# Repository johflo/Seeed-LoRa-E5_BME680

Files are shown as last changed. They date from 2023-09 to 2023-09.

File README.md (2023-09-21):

Seeed Wio E5 LoraWan BME680 node without seperate MCU.
Data from the BM680 is sent through the Helium LoraWan network to Cayenne to visualize the measured data

PCB designed with KiCad, assembled by seeedstudio (https://github.com/Seeed-Studio)

Next steps todo:
- testing low power consumption (low current measurement equipment needed like https://github.com/nfhw/tinycurrent)
- rework pcb to shrink it
- connection to Datacake instead of directly to Helium

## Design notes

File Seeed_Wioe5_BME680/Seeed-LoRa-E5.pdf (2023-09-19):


14/07/2022

Seeed-LoRa-E5 Project
Configuration Report

## 1. Description

### 1.1. Project

Project Name | Seeed-LoRa-E5
Board Name | custom
Generated with: | STM32CubeMX 6.6.1
Date | 07/14/2022

### 1.2. MCU

MCU Series | STM32WL
MCU Line | STM32WLEx
MCU name | STM32WLE5JCIx
MCU Package | UFBGA73
MCU Pin number | 73

### 1.3. Core(s) information

Core(s) | ARM Cortex-M4

## 2. Pinout Configuration

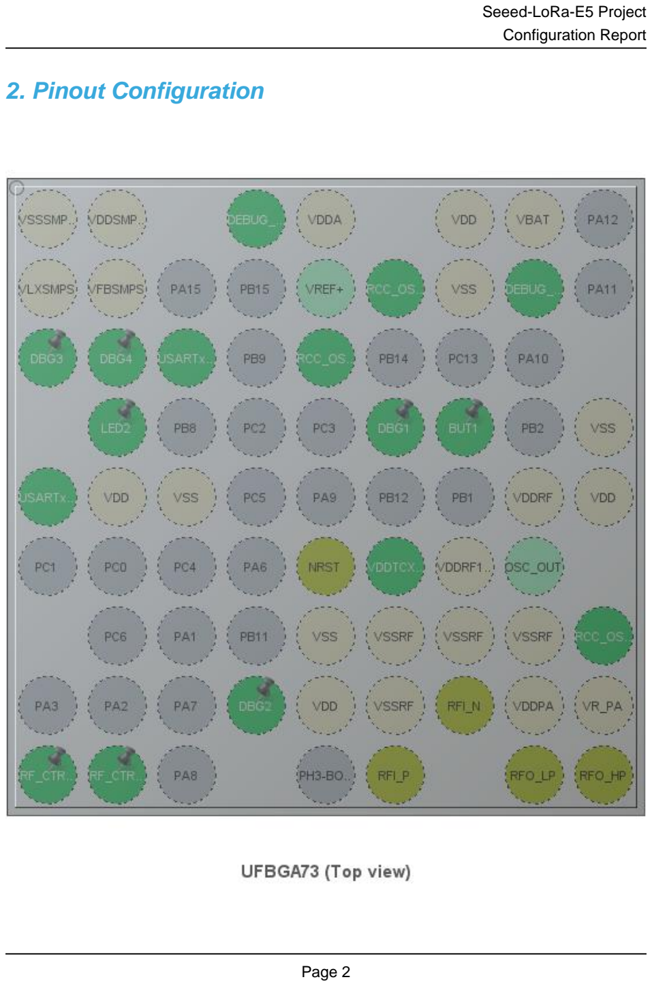
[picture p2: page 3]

## 3. Pins Configuration

Pin Number UFBGA73 | Pin Name (function after reset) | Pin Type | Alternate Function(s) | Label
A1 | VSSSMPS | Power
A2 | VDDSMPS | Power
A4 | PA14 | I/O | DEBUG_JTCK-SWCLK
A5 | VDDA | Power
A7 | VDD | Power
A8 | VBAT | Power
B1 | VLXSMPS | Power
B2 | VFBSMPS | Power
B6 | PC14-OSC32_IN | I/O | RCC_OSC32_IN
B7 | VSS | Power
B8 | PA13 | I/O | DEBUG_JTMS-SWDIO
C1 | PB3 * | I/O | GPIO_Output | DBG3
C2 | PB4 * | I/O | GPIO_Output | DBG4
C3 | PB7 | I/O | USART1_RX | USARTx_RX
C5 | PC15-OSC32_OUT | I/O | RCC_OSC32_OUT
D2 | PB5 * | I/O | GPIO_Output | LED2
D6 | PA0 * | I/O | GPIO_Output | DBG1
D7 | PB13 | I/O | GPIO_EXTI13 | BUT1
D9 | VSS | Power
E1 | PB6 | I/O | USART1_TX | USARTx_TX
E2 | VDD | Power
E3 | VSS | Power
E8 | VDDRF | Power
E9 | VDD | Power
F5 | NRST | Reset
F6 | PB0-VDD_TCXO | I/O | VDDTCXO
F7 | VDDRF1V55 | Power
G5 | VSS | Power
G6 | VSSRF | Power
G7 | VSSRF | Power
G8 | VSSRF | Power
G9 | OSC_IN | MonoIO | RCC_OSC_IN
H4 | PB10 * | I/O | GPIO_Output | DBG2
H5 | VDD | Power
H6 | VSSRF | Power
H7 | RFI_N | MonoIO

Pin Number UFBGA73 | Pin Name (function after reset) | Pin Type | Alternate Function(s) | Label
H8 | VDDPA | Power
H9 | VR_PA | Power
J1 | PA4 * | I/O | GPIO_Output | RF_CTRL1
J2 | PA5 * | I/O | GPIO_Output | RF_CTRL2
J6 | RFI_P | MonoIO
J8 | RFO_LP | MonoIO
J9 | RFO_HP | MonoIO

* The pin is affected with an I/O function

## 4. Clock Tree Configuration

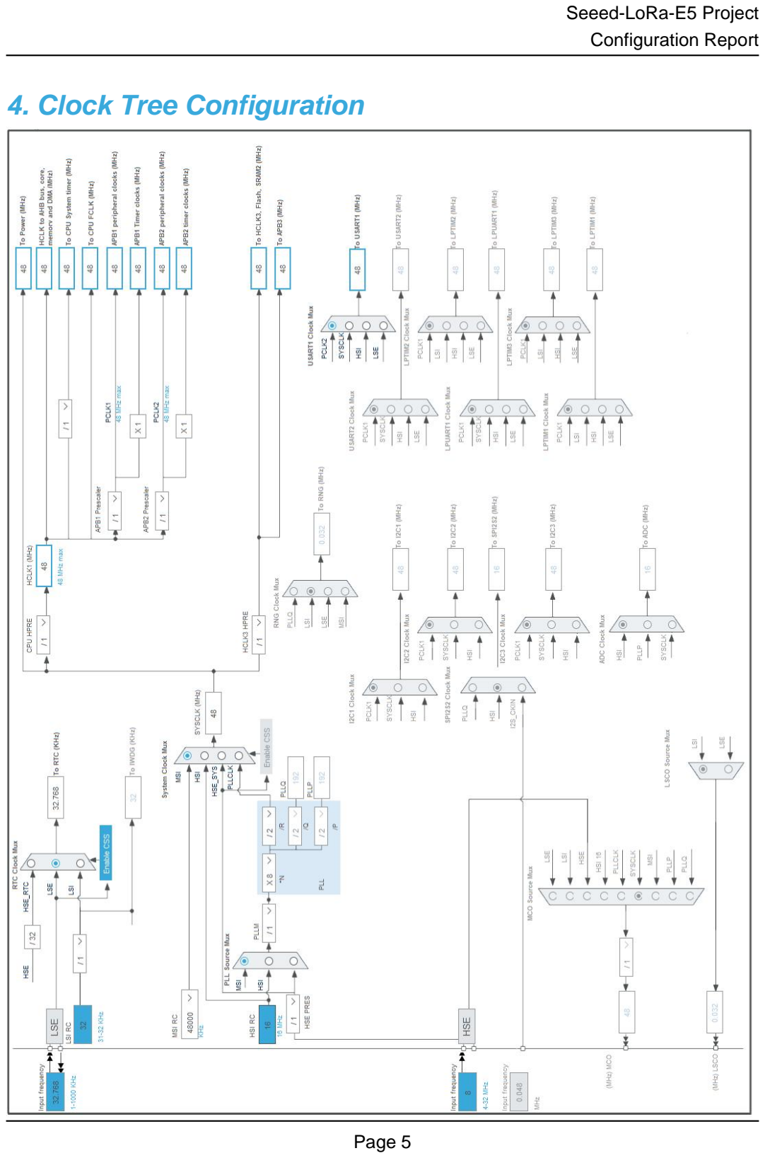
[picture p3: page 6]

## 5. Software Project

### 5.1. Project Settings

Name | Value
Project Name | Seeed-LoRa-E5
Project Folder | C:\Users\danam\STM32CubeIDE\workspace_1.7.0\Seeed-LoRa-E5
Toolchain / IDE | STM32CubeIDE
Firmware Package Name and Version | STM32Cube FW_WL V1.2.0
Application Structure | Advanced
Generate Under Root | Yes
Do not generate the main() | No
Minimum Heap Size | 0x200
Minimum Stack Size | 0x400

### 5.2. Code Generation Settings

Name | Value
STM32Cube MCU packages and embedded software | Copy only the necessary library files
Generate peripheral initialization as a pair of '.c/.h' files | Yes
Backup previously generated files when re-generating | Yes
Keep User Code when re-generating | Yes
Delete previously generated files when not re-generated | Yes
Set all free pins as analog (to optimize the power consumption) | No
Enable Full Assert | No

### 5.3. Advanced Settings - Generated Function Calls

Rank | Function Name | Peripheral Instance Name
1 | SystemClock_Config | RCC
2 | MX_GPIO_Init | GPIO
3 | MX_ADC_Init | ADC
4 | MX_RTC_Init | RTC
5 | MX_DMA_Init | DMA
6 | MX_USART1_UART_Init | USART1
7 | MX_SUBGHZ_Init | SUBGHZ
8 | MX_LoRaWAN_Init | LORAWAN

## 6. Power Consumption Calculator report

### 6.1. Microcontroller Selection

Series | STM32WL
Line | STM32WLEx
MCU | STM32WLE5JCIx
Datasheet | DS13105_Rev7

### 6.2. Parameter Selection

Temperature | 25
Vdd | 3.0

### 6.3. Battery Selection

Battery | Li-SOCL2(AAA700)
Capacity | 700.0 mAh
Self Discharge | 0.08 %/month
Nominal Voltage | 3.6 V
Max Cont Current | 10.0 mA
Max Pulse Current | 30.0 mA
Cells in series | 1
Cells in parallel | 1

### 6.4. Sequence

Step | Step1 | Step2
Mode | RUN | STOP2
Vdd | 3.0 | 3.0
Voltage Source | Battery | Battery
Range | Range1-Medium/SMPS-OFF | NoRange
Fetch Type | SRAM1 | NA
CPU Frequency | 48 MHz | 0 Hz
Clock Configuration | MSI | ALL_CLOCKS_OFF
Clock Source Frequency | 48 MHz | 0 Hz
Peripherals
Additional Cons. | 0 mA | 0 mA
Average Current | 5.65 mA | 885 nA
Duration | 0.1 ms | 0.9 ms
DMIPS | 60.0 | 0.0
Ta Max | 124.47 | 125
Category | In DS Table | In DS Table

### 6.5. Results

Sequence Time | 1 ms | Average Current | 565.8 µA
Battery Life | 1 month, 21 days, 1 hour | Average DMIPS | 60.0 DMIPS

### 6.6. Chart

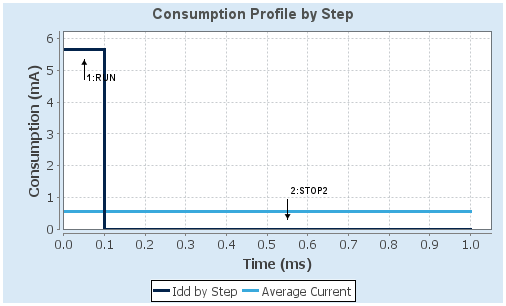
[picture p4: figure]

## 7. Peripherals and Middlewares Configuration

### 7.1. ADC

mode: Temperature Sensor Channel
mode: Vrefint Channel
7.1.1. Parameter Settings:

ADC_Settings:
Clock Prescaler | Synchronous clock mode divided by 4 *
Resolution | ADC 12-bit resolution
Calibration | Disable
Data Alignment | Right alignment
Scan Conversion Mode | Disabled
End Of Conversion Selection | End of single conversion
Low Power Auto Wait | Disabled
Auto Off | Disabled
Continuous Conversion Mode | Disabled
Discontinuous Conversion Mode | Disabled
External Trigger Conversion Source | Regular Conversion launched by software
External Trigger Conversion Edge | None
DMA Continuous Requests | Disabled
Overrun behaviour | Overrun data overwritten *
Sequencer | Sequencer set to fully configurable
SamplingTime Common 1 | 160.5 Cycles *
SamplingTime Common 2 | 160.5 Cycles *
Oversampling Mode | Disabled
Trigger Frequency | High frequency
ADC_Regular_ConversionMode:
Enable Regular Conversions | Disable

### 7.2. ADV_TRACE

mode: Enabled

### 7.3. DEBUG

JTAG and Trace: Serial Wire

### 7.4. MISC

mode: misc

### 7.5. RCC

High Speed Clock (HSE): TCXO
Low Speed Clock (LSE) : Crystal/Ceramic Resonator
7.5.1. Parameter Settings:

System Parameters:

VDD voltage (V) | 3.3
Instruction Cache | Enabled
Prefetch Buffer | Disabled
Data Cache | Enabled
Flash Latency(WS) | 2 WS (3 CPU cycle)
RCC Parameters:
HSI Calibration Value | 64
MSI Calibration Value | 0
MSI Auto Calibration | Enabled
HSE Startup Timout Value (ms) | 100
LSE Startup Timout Value (ms) | 5000
LSE Drive Capability | LSE oscillator low drive capability
Power Parameters:
Power Regulator Voltage Scale | Power Regulator Voltage Scale 1

### 7.6. RTC

mode: Activate Clock Source
mode: Activate Calendar
Alarm A: Internal Alarm A
7.6.1. Parameter Settings:

General:

Asynchronous Predivider value | RTC_PREDIV_A *
Bin Mode | Free running Binary mode *
SSRU Underflow Interrupt | Enabled
Alarm A:
Free running 32 bit value | 0
Binary AutoControl | RTC_ALARMSUBSECONDBIN_AUTOCLR_NO *
Free running 32 bit mask | SS[31:0] are compared and must match to activate alarm.

### 7.7. SEQUENCER

mode: Enabled

### 7.8. SUBGHZ

mode: Activated
7.8.1. Parameter Settings:
Baudrate Prescaler Value | 4 *

### 7.9. SYS

Timebase Source: None

### 7.10. TIMER

mode: Enabled

### 7.11. TINY_LPM

mode: Enabled

### 7.12. USART1

Mode: Asynchronous
7.12.1. Parameter Settings:

Basic Parameters:

Baud Rate | 115200
Word Length | 8 Bits (including Parity)
Parity | None
Stop Bits | 1
Advanced Parameters:
Data Direction | Receive and Transmit
Over Sampling | 16 Samples
Single Sample | Disable
ClockPrescaler | 1
Fifo Mode | Enable *
Txfifo Threshold | 1 eighth full configuration

Rxfifo Threshold | 1 eighth full configuration
Advanced Features:
Auto Baudrate | Disable
TX Pin Active Level Inversion | Disable
RX Pin Active Level Inversion | Disable
Data Inversion | Disable
TX and RX Pins Swapping | Disable
Overrun | Enable
DMA on RX Error | Enable
MSB First | Disable

### 7.13. LORAWAN

mode: Enabled
7.13.1. LoRaWAN application:

Application selection:
Application | End Node skeleton *
Application configuration recommandations | !! Please read carefully Information panel below!!

board settings:

Send Tx on Timer or Button Evt | TX_ON_TIMER
Probes Lines in Platform Settings | true *
lora_app:
Active region | LORAMAC_REGION_US915 *
Transmition duty cycle | 10000
Application user port | 2
Switch class port | 3
Default class | CLASS_A
Default handler message state | Unconfirmed message
Handler Adaptive Data Rate | On
Default activation type | OTAA
Force rejoin at each reboot | true
Default Unicast ping slots periodicity | 4
Default reponse timeout for class b and class c confirmed downlink frames in milli seconds. | 8000
sys_conf:
Trace verbose level | VLEVEL_M
Enable Application Logging | true
Disable Low Power Mode | false
Enable Sensor | false

7.13.2. LoRaWAN commissioning:

Commissioning:

Public network | true
Current network ID | 0
se-identity:
Static Device EUI | false
App/Join EUI | 01, 01, 01, 01, 01, 01, 01, 01
Application key | 9B,0C,9A,82,E6,74,A5,11,B9,E 5,26,A9,11,87,EB,84 *
Network key | 8B,0C,9A,82,E6,74,A5,11,B9,E 5,26,A9,11,87,EB,84 *
Static Device Address | false
Network session key | 2B,7E,15,16,28,AE,D2,A6,AB,F7,15,88,0 9,CF,4F,3C
Application session key | 2B,7E,15,16,28,AE,D2,A6,AB,F7,15,88,0 9,CF,4F,3C

lorawan_conf:

Enable Key read access | true
7.13.3. LoRaWAN middleware:

lorawan_conf:

Region(s) selection | please select the desired region(s) in the list below
Region Asia freq: 923 | false
Region Australia freq: 915 | false
Region China freq: 470 | false
Region China freq: 779 | false
Region Europe freq: 433 | false
Region Europe freq: 868 | true
Region Korea freq: 920 | false
Region India freq: 865 | false
Region USA freq: 915 | true
Region Russia freq: 864 | false
Enable Hybrid mode | false
Enable LoRaMAC ClassB | false
Enable the context management storage | true *
Select the LoRaWAN Link Layer specification version | v1.0.4 *
radio_conf:

Radio maximum wakeup time (in ms) | 1
radio_board_if:
Select radio Driver | Bsp via extSettings *
mw_log_conf:
Enable Middleware log | true
7.13.4. Platform Settings:
ADC | ADC
RTC | RTC
USART | USART1
Debug Line 1 | PA0
Debug Line 2 | PB10
Debug Line 3 | PB3
Debug Line 4 | PB4

* User modified value

## 8. System Configuration

### 8.1. GPIO configuration

IP | Pin | Signal | GPIO mode | GPIO pull/up pull down | Max Speed | User Label
DEBUG | PA14 | DEBUG_JTCK-SWCLK | n/a | n/a | n/a
| PA13 | DEBUG_JTMS-SWDIO | n/a | n/a | n/a
RCC | PC14-OSC32_IN | RCC_OSC32_IN | n/a | n/a | n/a
| PC15-OSC32_OU T | RCC_OSC32_O UT | n/a | n/a | n/a
| PB0-VDD_TCXO | VDDTCXO | n/a | n/a | n/a
| OSC_IN | RCC_OSC_IN | n/a | n/a | n/a
USART1 | PB7 | USART1_RX | Alternate Function Push Pull | No pull-up and no pull-down | Very High * | USARTx_RX
| PB6 | USART1_TX | Alternate Function Push Pull | No pull-up and no pull-down | Very High * | USARTx_TX
| | | | | * | DBG3
| PB4 | GPIO_Output | Output Push Pull | No pull-up and no pull-down | Very High * | DBG4
| PB5 | GPIO_Output | Output Push Pull | No pull-up and no pull-down | Very High * | LED2
| PA0 | GPIO_Output | Output Push Pull | No pull-up and no pull-down | Very High * | DBG1
| PB13 | GPIO_EXTI13 | External Interrupt Mode with Falling edge trigger detection | Pull-up * | n/a | BUT1
| PB10 | GPIO_Output | Output Push Pull | No pull-up and no pull-down | Very High * | DBG2
| PA4 | GPIO_Output | Output Push Pull | No pull-up and no pull-down | Very High * | RF_CTRL1
| PA5 | GPIO_Output | Output Push Pull | No pull-up and no pull-down | Very High * | RF_CTRL2
GPIO | PB3 | GPIO_Output | Output Push Pull | No pull-up and no pull-down | Very High

### 8.2. DMA configuration

DMA request | Stream | Direction | Priority
USART1_TX | DMA1_Channel1 | Memory To Peripheral | Low

USART1_TX: DMA1_Channel1 DMA request Settings:

Mode: | Normal
Peripheral Increment: | Disable
Memory Increment: | Enable *
Peripheral Data Width: | Byte
Memory Data Width: | Byte

### 8.3. NVIC configuration

8.3.1. NVIC
Interrupt Table | Enable | Preenmption Priority | SubPriority
Non maskable interrupt | true | 0 | 0
Hard fault interrupt | true | 0 | 0
Memory management fault | true | 0 | 0
Prefetch fault, memory access fault | true | 0 | 0
Undefined instruction or illegal state | true | 0 | 0
System service call via SWI instruction | true | 0 | 0
Debug monitor | true | 0 | 0
Pendable request for system service | true | 0 | 0
System tick timer | true | 15 | 0
RTC Tamper, RTC TimeStamp, LSECSS and RTC SSRU Interrupts | true | 0 | 0
DMA1 Channel 1 Interrupt | true | 2 | 0
USART1 Interrupt | true | 2 | 0
EXTI Lines [15:10] Interrupt | true | 0 | 0
RTC Alarms (A and B) Interrupt | true | 0 | 0
SUBGHZ Radio Interrupt | true | 0 | 0
PVD and PVM detector | | unused
FLASH (CFI) global Interrupt | | unused
RCC Interrupt | | unused
ADC Interrupt | | unused
8.3.2. NVIC Code generation

Enabled interrupt Table Select for init sequence ordering

| | Generate IRQ
| | handler | Call HAL handler
Non maskable interrupt | false | true | false
Hard fault interrupt | false | true | false
Memory management fault | false | true | false
Prefetch fault, memory access fault | false | true | false
Undefined instruction or illegal state | false | true | false
System service call via SWI instruction | false | true | false
Debug monitor | false | true | false
Pendable request for system service | false | true | false
System tick timer | false | true | false
RTC Tamper, RTC TimeStamp, LSECSS and RTC SSRU Interrupts | false | true | true
DMA1 Channel 1 Interrupt | false | true | true
USART1 Interrupt | false | true | true

Enabled interrupt Table | Select for init sequence ordering | Generate IRQ handler | Call HAL handler
EXTI Lines [15:10] Interrupt | false | true | true
RTC Alarms (A and B) Interrupt | false | true | true
SUBGHZ Radio Interrupt | false | true | true

* User modified value

## 9. System Views

9.1. Category view
9.1.1. Current

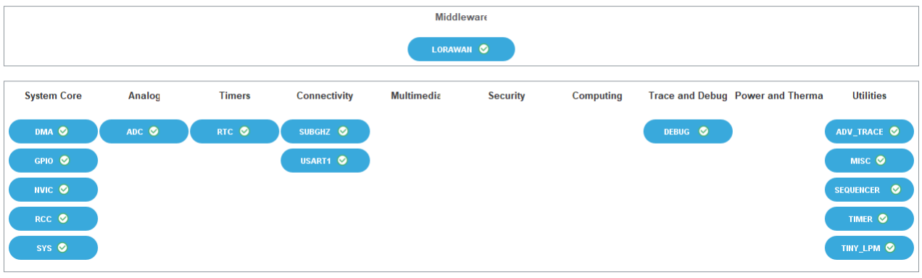
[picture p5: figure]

## 10. Docs & Resources

Type | Link
Presentations | https://www.st.com/resource/en/product_presentation/stm32-stm8_embedded_software_solutions.pdf
Presentations | https://www.st.com/resource/en/product_presentation/stm32_eval-tools_portfolio.pdf
Presentations | https://www.st.com/resource/en/product_presentation/stm32_stm8_functi onal-safety-packages.pdf
Presentations | https://www.st.com/resource/en/product_presentation/stm32-stm8_software_development_tools.pdf
Presentations | https://www.st.com/resource/en/product_presentation/microcontrollers_stm32wl_series_product_overview.pdf
Presentations | https://www.st.com/resource/en/product_presentation/stm32cubemonitor-wireless-longrange_rftest.pdf
Flyers | https://www.st.com/resource/en/flyer/flnucleolrwan.pdf
Flyers | https://www.st.com/resource/en/flyer/flstm32nucleo.pdf
Flyers | https://www.st.com/resource/en/flyer/flstm32wl.pdf
Flyers | https://www.st.com/resource/en/flyer/flstm32wbvl.pdf
Application Notes | https://www.st.com/resource/en/application_note/an1181-electrostatic-discharge-sensitivity-measurement-stmicroelectronics.pdf
Application Notes | https://www.st.com/resource/en/application_note/an1709-emc-design-guide-for-stm8-stm32-and-legacy-mcus-stmicroelectronics.pdf
Application Notes | https://www.st.com/resource/en/application_note/an2606-stm32-microcontroller-system-memory-boot-mode-stmicroelectronics.pdf
Application Notes | https://www.st.com/resource/en/application_note/an2639-soldering-recommendations-and-package-information-for-leadfree-ecopack-mcus-and-mpus-stmicroelectronics.pdf
Application Notes | https://www.st.com/resource/en/application_note/an2834-how-to-get-the-best-adc-accuracy-in-stm32-microcontrollers-stmicroelectronics.pdf
Application Notes | https://www.st.com/resource/en/application_note/an2867-oscillator-design-guide-for-stm8afals-stm32-mcus-and-mpus-stmicroelectronics.pdf

Application Notes | https://www.st.com/resource/en/application_note/an3126-audio-and-waveform-generation-using-the-dac-in-stm32-products-stmicroelectronics.pdf
Application Notes | https://www.st.com/resource/en/application_note/an3155-usart-protocol-used-in-the-stm32-bootloader-stmicroelectronics.pdf
Application Notes | https://www.st.com/resource/en/application_note/an4013-stm32-crossseries-timer-overview-stmicroelectronics.pdf
Application Notes | https://www.st.com/resource/en/application_note/an4229-how-to-implement-a-vocoder-solution-using-stm32-microcontrollers-stmicroelectronics.pdf
Application Notes | https://www.st.com/resource/en/application_note/an4286-spi-protocol-used-in-the-stm32-bootloader-stmicroelectronics.pdf
Application Notes | https://www.st.com/resource/en/application_note/an4655-virtually-increasing-the-number-of-serial-communication-peripherals-in-stm32-applications-stmicroelectronics.p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
Application Notes | https://www.st.com/resource/en/application_note/an4750-handling-of-soft-errors-in-stm32-applications-stmicroelectronics.pdf
Application Notes | https://www.st.com/resource/en/application_note/an4759-using-the-hardware-realtime-clock-rtc-and-the-tamper-management-unit-tamp-with-stm32-microcontrollers-stmicroe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
Application Notes | https://www.st.com/resource/en/application_note/an4776-generalpurpose-timer-cookbook-for-stm32-microcontrollers-stmicroelectronics.pdf
Application Notes | https://www.st.com/resource/en/application_note/an4803-highspeed-si-simulations-using-ibis-and-boardlevel-simulations-using-hyperlynx-si-on-stm32-mcus-and-mpus-stmic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
Application Notes | https://www.st.com/resource/en/application_note/an4894-eeprom-emulation-techniques-and-software-for-stm32-microcontrollers-stmicroelectronics.pdf
Application Notes | https://www.st.com/resource/en/application_note/an5027-interfacing-pdm-digital-microphones-using-stm32-mcus-and-mpus-stmicroelectronics.pdf
Application Notes | https://www.st.com/resource/en/application_note/an5036-thermal-management-guidelines-for-stm32-applications-stmicroelectronics.pdf
Application Notes | https://www.st.com/resource/en/application_note/an5042-precise-hse-

| frequency-and-startup-time-tuning-for-stm32-wireless-mcus-stmicroelectronics.pdf
Application Notes | https://www.st.com/resource/en/application_note/an5156-introduction-to-stm32-microcontrollers-security-stmicroelectronics.pdf
Application Notes | https://www.st.com/resource/en/application_note/an5225-usb-typec-power-delivery-using-stm32-mcus-and-mpus-stmicroelectronics.pdf
Application Notes | https://www.st.com/resource/en/application_note/an5406-how-to-build-a-lora-application-with-stm32cubewl-stmicroelectronics.pdf
Application Notes | https://www.st.com/resource/en/application_note/an5407-optimized-rf-board-layout-for-stm32wl-series-stmicroelectronics.pdf
Application Notes | https://www.st.com/resource/en/application_note/an5408-migrating-from-stm32l0-stm32l1-and-stm32l4-series-associated-with-sx12xx-transceivers-to-stm32wl-series-microc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
Application Notes | https://www.st.com/resource/en/application_note/an5409-stm32cube-mcu-package-examples-for-stm32wl-series-stmicroelectronics.pdf
Application Notes | https://www.st.com/resource/en/application_note/an5457-rf-matching-network-design-guide-for-stm32wl-series-stmicroelectronics.pdf
Application Notes | https://www.st.com/resource/en/application_note/an5480-how-to-build-a-sigfox-application-with-stm32cubewl-stmicroelectronics.pdf
Application Notes | https://www.st.com/resource/en/application_note/an5543-enhanced-methods-to-handle-spi-communication-on-stm32-devices-stmicroelectronics.pdf
Application Notes | https://www.st.com/resource/en/application_note/an5568-ultralowpower-features-of-stm32wl-series-microcontrollers-stmicroelectronics.pdf
Application Notes | https://www.st.com/resource/en/application_note/an5690-vrefbuf-peripheral-applications-and-trimming-technique-stmicroelectronics.pdf
Application Notes | https://www.st.com/resource/en/application_note/an5664-rssi-and-snr-for-lora-modulation-on-stm32wl-series-stmicroelectronics.pdf
Application Notes | https://www.st.com/resource/en/application_note/an4899-stm32-microcontroller-gpio-hardware-settings-and-lowpower-consumption-stmicroelectronics.pdf

Application Notes
for related Tools

https://www.st.com/resource/en/application_note/an1202_freertos_guidefreertos-guide-stmicroelectronics.pdf

& Software
Application Notes for related Tools & Software | https://www.st.com/resource/en/application_note/an1602_semihosting_in_truestudio-how-to-do-semihosting-in-truestudio-stmicroelectronics.pdf
Application Notes for related Tools & Software | https://www.st.com/resource/en/application_note/an1801_stm32cubeprogrammer_in_truestudio-installing-stm32cubeprogrammer-in-truestudio-stmicroelectronics.pdf
Application Notes for related Tools & Software | https://www.st.com/resource/en/application_note/atollic_editing_keyboard_shortcuts-atollic-editing-keyboard-shortcuts-stmicroelectronics.pdf
Application Notes for related Tools & Software | https://www.st.com/resource/en/application_note/iar_to_atollic_truestudio_migration_guide-truestudio-for-arm-migration-guide-iar-embedded-workbench-to-truestudio-stm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
Application Notes for related Tools & Software | https://www.st.com/resource/en/application_note/stm32cubemx_installation_in_truestudio-stm32cubemx-installation-in-truestudio-stmicroelectronics.pdf
Application Notes for related Tools & Software | https://www.st.com/resource/en/application_note/an4502-stm32-smbuspmbus-embedded-software-expansion-for-stm32cube-stmicroelectronics.pdf
Application Notes for related Tools & Software | https://www.st.com/resource/en/application_note/an4657-stm32-inapplication-programming-iap-using-the-usart-stmicroelectronics.pdf
Application Notes for related Tools & Software | https://www.st.com/resource/en/application_note/an4759-using-the-hardware-realtime-clock-rtc-and-the-tamper-management-unit-tamp-with-stm32-microcontrollers-stmicroe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
Application Notes for related Tools & Software | https://www.st.com/resource/en/application_note/an4841-digital-signal-processing-for-stm32-microcontrollers-using-cmsis-stmicroelectronics.pdf
Application Notes for related Tools & Software | https://www.st.com/resource/en/application_note/an4894-eeprom-emulation-techniques-and-software-for-stm32-microcontrollers-stmicroelectronics.pdf
Application Notes for related Tools & Software | https://www.st.com/resource/en/application_note/an5042-precise-hse-frequency-and-startup-time-tuning-for-stm32-wireless-mcus-stmicroelectronics.pdf

Application Notes for related Tools & Software | https://www.st.com/resource/en/application_note/an5054-secure-programming-using-stm32cubeprogrammer-stmicroelectronics.pdf
Application Notes for related Tools & Software | https://www.st.com/resource/en/application_note/an5360-getting-started-with-projects-based-on-the-stm32mp1-series-in-stm32cubeide-stmicroelectronics.pdf
Application Notes for related Tools & Software | https://www.st.com/resource/en/application_note/an5361-getting-started-with-projects-based-on-dualcore-stm32h7-microcontrollers-in-stm32cubeide-stmicroelectronics.pd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
Application Notes for related Tools & Software | https://www.st.com/resource/en/application_note/an5394-getting-started-with-projects-based-on-the-stm32l5-series-in-stm32cubeide-stmicroelectronics.pdf
Application Notes for related Tools & Software | https://www.st.com/resource/en/application_note/an5406-how-to-build-a-lora-application-with-stm32cubewl-stmicroelectronics.pdf
Application Notes for related Tools & Software | https://www.st.com/resource/en/application_note/an5409-stm32cube-mcu-package-examples-for-stm32wl-series-stmicroelectronics.pdf
Application Notes for related Tools & Software | https://www.st.com/resource/en/application_note/an5418-how-to-build-a-simple-usbpd-sink-application-with-stm32cubemx-stmicroelectronics.pdf
Application Notes for related Tools & Software | https://www.st.com/resource/en/application_note/an5426-migrating-graphics-middleware-projects-from-stm32cubemx-540-to-stm32cubemx-550-stmicroelectronics.pdf
Application Notes for related Tools & Software | https://www.st.com/resource/en/application_note/an5480-how-to-build-a-sigfox-application-with-stm32cubewl-stmicroelectronics.pdf
Application Notes for related Tools & Software | https://www.st.com/resource/en/application_note/an5481-lorawan-at-commands-for-stm32cubewl-stmicroelectronics.pdf
Application Notes for related Tools & Software | https://www.st.com/resource/en/application_note/an5544-integration-guide-of-sbsfu-on-stm32cubewl-including-kms-stmicroelectronics.pdf
Application Notes | https://www.st.com/resource/en/application_note/an5554-lorawan-

for related Tools & Software | firmware-update-over-the-air-with-stm32cubewl-stmicroelectronics.pdf
Application Notes for related Tools & Software | https://www.st.com/resource/en/application_note/an5564-getting-started-with-projects-based-on-dualcore-stm32wl-microcontrollers-in-stm32cubeide-stmicroelectronics.pd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
Application Notes for related Tools & Software | https://www.st.com/resource/en/application_note/an5566-rf-certification-process-for-nucleowl55jc-stmicroelectronics.pdf
Application Notes for related Tools & Software | https://www.st.com/resource/en/application_note/an5682-how-to-secure-lorawan-and-sigfox-with-stm32cubewl-stmicroelectronics.pdf
Application Notes for related Tools & Software | https://www.st.com/resource/en/application_note/an5687-longpacket-operation-with-stm32cubewl-stmicroelectronics.pdf
Application Notes for related Tools & Software | https://www.st.com/resource/en/application_note/an5731-stm32cubemx-and-stm32cubeide-threadsafe-solution-stmicroelectronics.pdf
Errata Sheets | https://www.st.com/resource/en/errata_sheet/es0506-stm32wle5xx-stm32wle4xx-device-errata-stmicroelectronics.pdf
Datasheet | https://www.st.com/resource/en/datasheet/dm00648230.pdf
Programming Manuals | https://www.st.com/resource/en/programming_manual/pm0214-stm32-cortexm4-mcus-and-mpus-programming-manual-stmicroelectronics.pdf
Programming Manuals | https://www.st.com/resource/en/programming_manual/pm0223-cortexm0-programming-manual-for-stm32l0-stm32g0-stm32wl-and-stm32wb-series-stmicroelectronics.pdf
Reference Manuals | https://www.st.com/resource/en/reference_manual/rm0461-stm32wlex-advanced-armbased-32bit-mcus-with-subghz-radio-solution-stmicroelectronics.pdf
Technical Notes & Articles | https://www.st.com/resource/en/technical_note/tn1163-description-of-wlcsp-for-microcontrollers-and-recommendations-for-its-use-stmicroelectronics.pdf
Technical Notes & Articles | https://www.st.com/resource/en/technical_note/tn1204-tape-and-reel-shipping-media-for-stm32-microcontrollers-in-bga-packages-stmicroelectronics.pdf

Technical Notes & Articles | https://www.st.com/resource/en/technical_note/tn1205-tape-and-reel-shipping-media-for-stm8-and-stm32-microcontrollers-in-fpn-packages-stmicroelectronics.pdf
Technical Notes & Articles | https://www.st.com/resource/en/technical_note/tn1206-tape-and-reel-shipping-media-for-stm8-and-stm32-microcontrollers-in-qfp-packages-stmicroelectronics.pdf
Technical Notes & Articles | https://www.st.com/resource/en/technical_note/tn1207-tape-and-reel-shipping-media-for-stm8-and-stm32-microcontrollers-in-so-packages-stmicroelectronics.pdf
Technical Notes & Articles | https://www.st.com/resource/en/technical_note/tn1208-tape-and-reel-shipping-media-for-stm8-and-stm32-microcontrollers-in-tssop-and-ssop-packages-stmicroelectronics.p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

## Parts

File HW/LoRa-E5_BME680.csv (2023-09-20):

Item | Qty | Reference(s) | Value | LibPart | Footprint | Datasheet | MPN | SKU
 |  | AE1 | Antenna | Device:Antenna | Sonstige:Johanson 0868AT43A0020 | ~ | 0868AT43A0020
 |  | BT1 | Battery_Cell | Device:Battery_Cell | Battery:BatteryHolder_Keystone_3008_1x2450 | ~ | MY-2450-01
 |  | C1 | 100nF | Device:C | Capacitor_SMD:C_0402_1005Metric | ~ |  | 302010004
 |  | C3 | 4.7µF | Device:C | Capacitor_SMD:C_0402_1005Metric | ~ |  | 302010111
 |  | C4 | 100nF | Device:C | Capacitor_SMD:C_0402_1005Metric | ~ |  | 302010004
 |  | C5 | 100nF | Device:C | Capacitor_SMD:C_0402_1005Metric | ~ |  | 302010004
 |  | J1 | Conn_01x06 | Connector_Generic:Conn_01x06 | Connector_PinHeader_2.54mm:PinHeader_1x06_P2.54mm_Vertical | ~
 |  | J2 | Conn_01x04 | Connector_Generic:Conn_01x04 | Connector_PinHeader_2.54mm:PinHeader_1x04_P2.54mm_Vertical | ~
 |  | R1 | 4k7 | Device:R | Resistor_SMD:R_0603_1608Metric | ~ |  | 301010290
 |  | R2 | 4k7 | Device:R | Resistor_SMD:R_0603_1608Metric | ~ |  | 301010290
 |  | SW1 | RST | Switch:SW_Push | Sonstige:Alps 5.2x5.2 | ~ | SKQGAFE010
 |  | U1 | LoRa-E5 | LoRa-E5:LoRa-E5 | LoRa-E5:LoRa-E5 |  |  | 317990829
 |  | U2 | BME680 | Sensor:BME680 | Package_LGA:Bosch_LGA-8_3x3mm_P0.8mm_ClockwisePinNumbering | https://ae-bst.resource.bosch.com/media/_tech/media/datasheets/BST-BME680-DS001.pdf | BME680
Collated Components:
Item | Qty | Reference(s) | Value | LibPart | Footprint | Datasheet | MPN | SKU
1 | 1 | AE1 | Antenna | Device:Antenna | Sonstige:Johanson 0868AT43A0020 | ~ | 0868AT43A0020
2 | 1 | BT1 | Battery_Cell | Device:Battery_Cell | Battery:BatteryHolder_Keystone_3008_1x2450 | ~ | MY-2450-01
3 | 3 | C1, C4, C5 | 100nF | Device:C | Capacitor_SMD:C_0402_1005Metric | ~ |  | 302010004
4 | 1 | C3 | 4.7µF | Device:C | Capacitor_SMD:C_0402_1005Metric | ~ |  | 302010111
5 | 1 | J1 | Conn_01x06 | Connector_Generic:Conn_01x06 | Connector_PinHeader_2.54mm:PinHeader_1x06_P2.54mm_Vertical | ~
6 | 1 | J2 | Conn_01x04 | Connector_Generic:Conn_01x04 | Connector_PinHeader_2.54mm:PinHeader_1x04_P2.54mm_Vertical | ~
7 | 2 | R1, R2 | 4k7 | Device:R | Resistor_SMD:R_0603_1608Metric | ~ |  | 301010290
8 | 1 | SW1 | RST | Switch:SW_Push | Sonstige:Alps 5.2x5.2 | ~ | SKQGAFE010
9 | 1 | U1 | LoRa-E5 | LoRa-E5:LoRa-E5 | LoRa-E5:LoRa-E5 |  |  | 317990829
10 | 1 | U2 | BME680 | Sensor:BME680 | Package_LGA:Bosch_LGA-8_3x3mm_P0.8mm_ClockwisePinNumbering | https://ae-bst.resource.bosch.com/media/_tech/media/datasheets/BST-BME680-DS001.pdf | BME680

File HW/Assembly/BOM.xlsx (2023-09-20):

Designator | MPN/Seeed SKU | Qty | Link
AE1 | 0868AT43A0020E | 1 | https://www.mouser.at/ProductDetail/Johanson-Technology/0868AT43A0020E?qs=yCnrNFeXz%252BjNeWZ9KocNKw%3D%3D
BT1 | 3008 | 1 | https://www.mouser.at/ProductDetail/Keystone-Electronics/3008?qs=Mn60vILZNNaVxpUY7xQk0w%3D%3D
C1, C4, C5 | 302010004 | 3
C3 | 302010111 | 1
R1, R2 | 301010290 | 2
SW1 | K2-1187SQ-A4SW-06 | 1 | https://file.elecfans.com/web1/M00/89/C6/o4YBAFyLiuyAH9G2AApeEw_-o0I052.PDF?filename=5bd02afaed4b6.PDF
U1 | 317990687 | 1
U2 | BME680 | 1 | https://www.mouser.at/ProductDetail/Bosch-Sensortec/BME680?qs=v271MhAjFHjo0yA%2FC4OnDQ%3D%3D

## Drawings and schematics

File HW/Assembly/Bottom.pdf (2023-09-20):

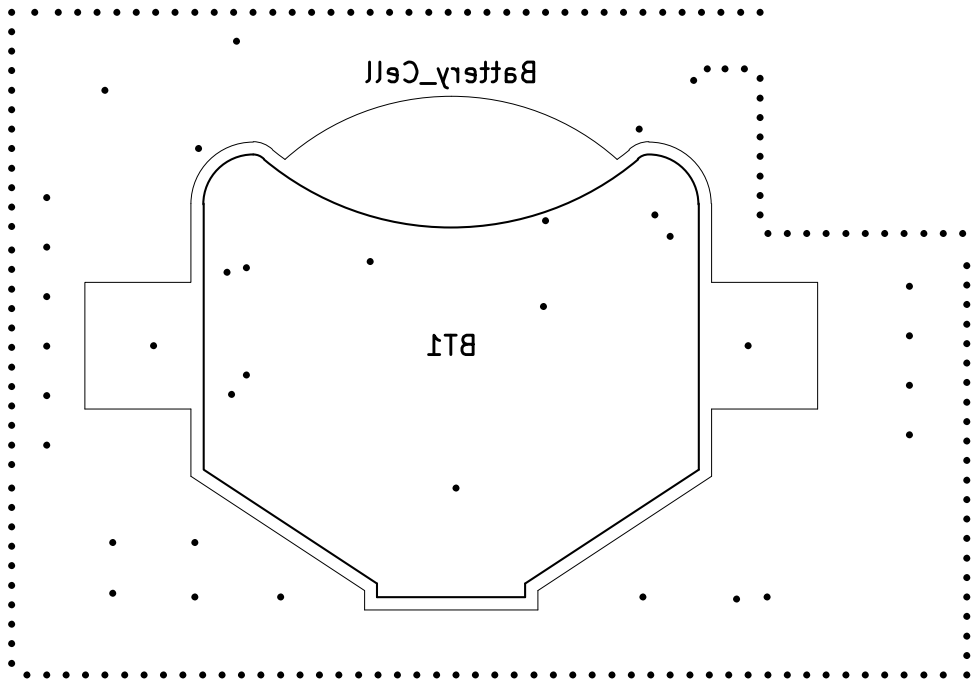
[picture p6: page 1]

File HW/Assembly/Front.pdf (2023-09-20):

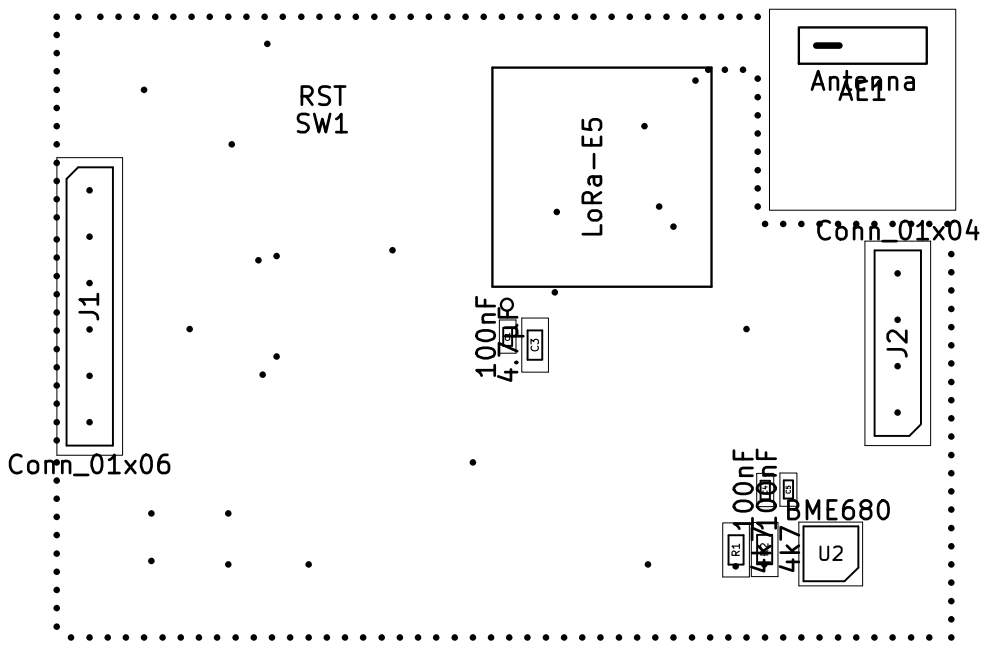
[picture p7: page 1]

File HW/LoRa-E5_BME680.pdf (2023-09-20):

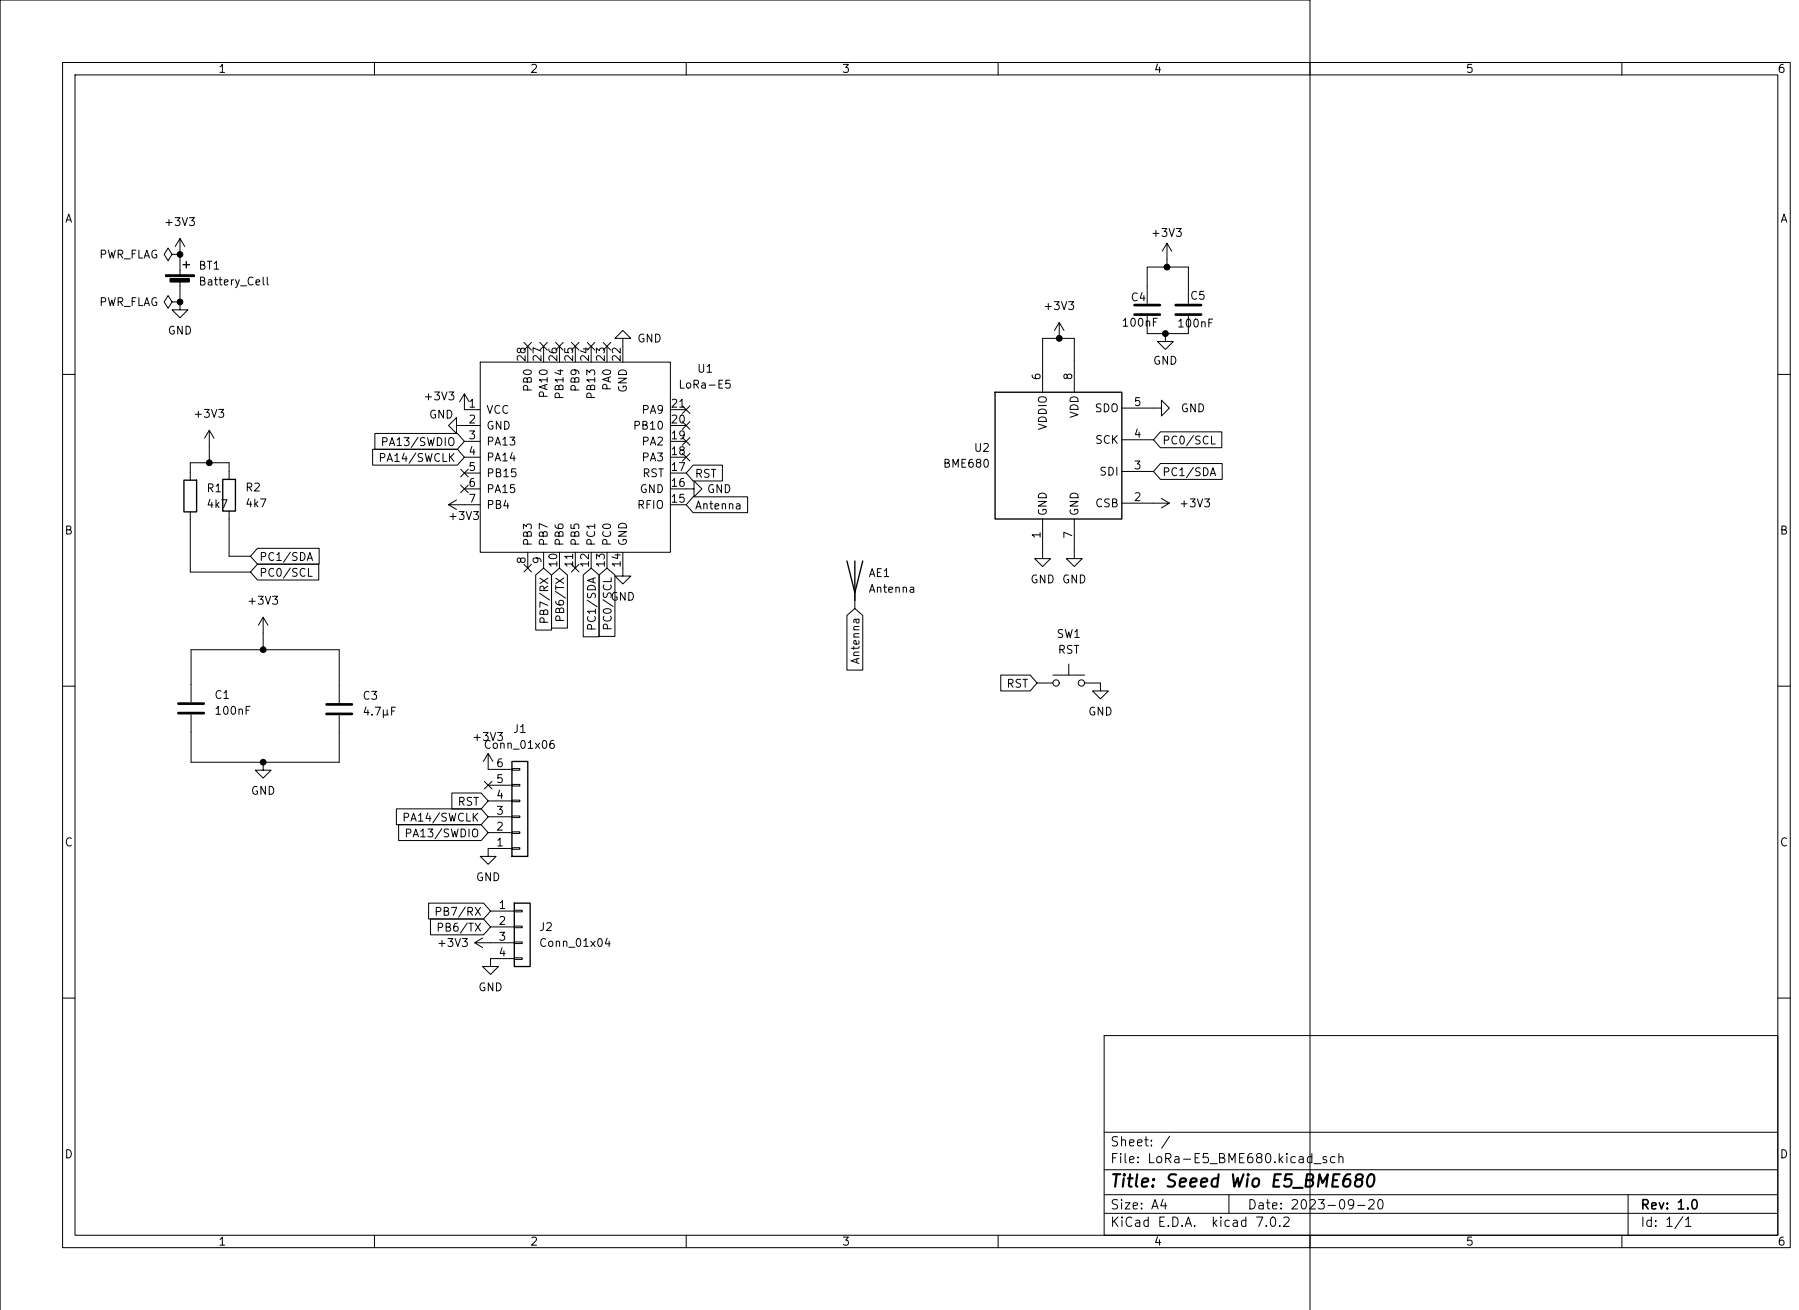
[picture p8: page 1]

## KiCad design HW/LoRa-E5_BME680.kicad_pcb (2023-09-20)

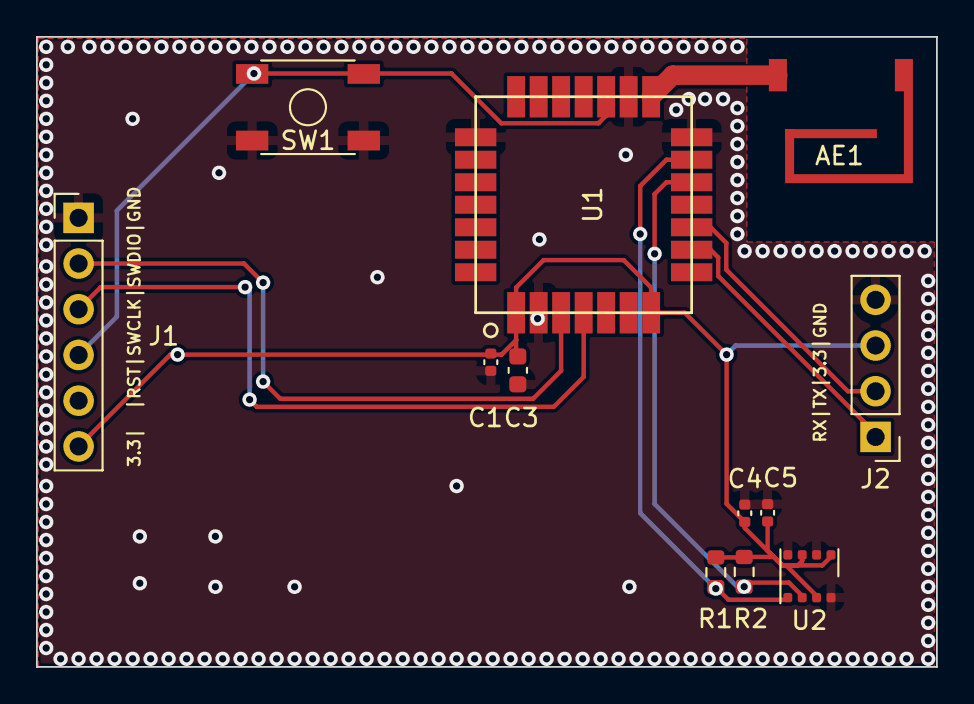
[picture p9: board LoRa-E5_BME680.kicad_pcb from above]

Board: 2 copper layers, 50.0 x 35.0 mm, 13 parts (1 on the bottom side), 10 nets.

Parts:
AE1: Antenna; Johanson 0868AT43A0020
BT1: Battery_Cell; BatteryHolder_Keystone_3008_1x2450
C1, C4, C5: 100nF; C_0402_1005Metric
C3: 4.7µF; C_0603_1608Metric
J1: Conn_01x06; PinHeader_1x06_P2.54mm_Vertical
J2: Conn_01x04; PinHeader_1x04_P2.54mm_Vertical
R1, R2: 4k7; R_0603_1608Metric
SW1: RST; Alps 5.2x5.2
U1: LoRa-E5
U2: BME680; Bosch_LGA-8_3x3mm_P0.8mm_ClockwisePinNumbering

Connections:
+3V3: BT1.1 (+), C1.1, C3.1, C4.2, C5.2, J1.6, J2.3, R1.2, R2.2, U1.1 (VCC), U1.7 (PB4), U2.2 (CSB), U2.6 (VDDIO), U2.8 (VDD)
Antenna: AE1.1 (A), U1.15 (RFIO)
GND: BT1.2 (-), C1.2, C3.2, C4.1, C5.1, J1.1, J2.4, SW1.2, U1.2 (GND), U1.14 (GND), U1.16 (GND), U1.22 (GND), U2.1 (GND), U2.5 (SDO), U2.7 (GND)
PA13/SWDIO: J1.2, U1.3 (PA13)
PA14/SWCLK: J1.3, U1.4 (PA14)
PB6/TX: J2.2, U1.10 (PB6)
PB7/RX: J2.1, U1.9 (PB7)
PC0/SCL: R1.1, U1.13 (PC0), U2.4 (SCK)
PC1/SDA: R2.1, U1.12 (PC1), U2.3 (SDI)
RST: J1.4, SW1.1, U1.17 (RST)

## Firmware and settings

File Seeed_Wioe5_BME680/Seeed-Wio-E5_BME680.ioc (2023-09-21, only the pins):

Mcu.UserName=STM32WLE5JCIx
PA0.GPIO_Label=DBG1
PA0.Signal=GPIO_Output
PA4.GPIO_Label=RF_CTRL1
PA4.Signal=GPIO_Output
PA5.GPIO_Label=RF_CTRL2
PA5.Signal=GPIO_Output
PB0-VDD_TCXO.Signal=VDDTCXO
PB10.GPIO_Label=DBG2
PB10.Signal=GPIO_Output
PB3.GPIO_Label=DBG3
PB3.Signal=GPIO_Output
PB4.GPIO_Label=DBG4
PB4.Signal=GPIO_Output
PB5.Signal=GPIO_Output
PB6.GPIO_Label=USARTx_TX
PB6.Signal=USART1_TX
PB7.GPIO_Label=USARTx_RX
PB7.Signal=USART1_RX
PC0.Signal=I2C3_SCL
PC1.Signal=I2C3_SDA
PC14-OSC32_IN.Signal=RCC_OSC32_IN
PC15-OSC32_OUT.Signal=RCC_OSC32_OUT

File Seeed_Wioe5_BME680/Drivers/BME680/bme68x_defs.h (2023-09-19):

/**
* Copyright (c) 2021 Bosch Sensortec GmbH. All rights reserved.
*
* BSD-3-Clause
*
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
* 1. Redistributions of source code must retain the above copyright
*    notice, this list of conditions and the following disclaimer.
*
* 2. Redistributions in binary form must reproduce the above copyright
*    notice, this list of conditions and the following disclaimer in the
*    documentation and/or other materials provided with the distribution.
*
* 3. Neither the name of the copyright holder nor the names of its
*    contributors may be used to endorse or promote products derived from
*    this software without specific prior written permission.
*
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
* @file       bme68x_defs.h
* @date       2021-11-09
* @version    v4.4.7
*
*/

/*! @cond DOXYGEN_SUPRESS */

#ifndef BME68X_DEFS_H_
#define BME68X_DEFS_H_

/********************************************************* */
/*!             Header includes                           */
/********************************************************* */
#ifdef __KERNEL__
#include <linux/types.h>
#include <linux/kernel.h>
#else
#include <stdint.h>
#include <stddef.h>
#endif

/********************************************************* */
/*!               Common Macros                           */
/********************************************************* */
#ifdef __KERNEL__
#if !defined(UINT8_C) && !defined(INT8_C)
#define INT8_C(x)    S8_C(x)
#define UINT8_C(x)   U8_C(x)
#endif

#if !defined(UINT16_C) && !defined(INT16_C)
#define INT16_C(x)   S16_C(x)
#define UINT16_C(x)  U16_C(x)
#endif

#if !defined(INT32_C) && !defined(UINT32_C)
#define INT32_C(x)   S32_C(x)
#define UINT32_C(x)  U32_C(x)
#endif

#if !defined(INT64_C) && !defined(UINT64_C)
#define INT64_C(x)   S64_C(x)
#define UINT64_C(x)  U64_C(x)
#endif
#endif

/*! C standard macros */
#ifndef NULL
#ifdef __cplusplus
#define NULL         0
#else
#define NULL         ((void *) 0)
#endif
#endif

#ifndef BME68X_DO_NOT_USE_FPU

/* Comment or un-comment the macro to provide floating point data output */
#define BME68X_USE_FPU
#endif

/* Period between two polls (value can be given by user) */
#ifndef BME68X_PERIOD_POLL
#define BME68X_PERIOD_POLL                        UINT32_C(10000)
#endif

/* BME68X unique chip identifier */
#define BME68X_CHIP_ID                            UINT8_C(0x61)

/* Period for a soft reset */
#define BME68X_PERIOD_RESET                       UINT32_C(10000)

/* BME68X lower I2C address */
#define BME68X_I2C_ADDR_LOW                       UINT8_C(0x76)

/* BME68X higher I2C address */
#define BME68X_I2C_ADDR_HIGH                      UINT8_C(0x77)

/* Soft reset command */
#define BME68X_SOFT_RESET_CMD                     UINT8_C(0xb6)

/* Return code definitions */
/* Success */
#define BME68X_OK                                 INT8_C(0)

/* Errors */
/* Null pointer passed */
#define BME68X_E_NULL_PTR                         INT8_C(-1)

/* Communication failure */
#define BME68X_E_COM_FAIL                         INT8_C(-2)

/* Sensor not found */
#define BME68X_E_DEV_NOT_FOUND                    INT8_C(-3)

/* Incorrect length parameter */
#define BME68X_E_INVALID_LENGTH                   INT8_C(-4)

/* Self test fail error */
#define BME68X_E_SELF_TEST                        INT8_C(-5)

/* Warnings */
/* Define a valid operation mode */
#define BME68X_W_DEFINE_OP_MODE                   INT8_C(1)

/* No new data was found */
#define BME68X_W_NO_NEW_DATA                      INT8_C(2)

/* Define the shared heating duration */
#define BME68X_W_DEFINE_SHD_HEATR_DUR             INT8_C(3)

/* Information - only available via bme68x_dev.info_msg */
#define BME68X_I_PARAM_CORR                       UINT8_C(1)

/* Register map addresses in I2C */
/* Register for 3rd group of coefficients */
#define BME68X_REG_COEFF3                         UINT8_C(0x00)

/* 0th Field address*/
#define BME68X_REG_FIELD0                         UINT8_C(0x1d)

/* 0th Current DAC address*/
#define BME68X_REG_IDAC_HEAT0                     UINT8_C(0x50)

/* 0th Res heat address */
#define BME68X_REG_RES_HEAT0                      UINT8_C(0x5a)

/* 0th Gas wait address */
#define BME68X_REG_GAS_WAIT0                      UINT8_C(0x64)

/* Shared heating duration address */
#define BME68X_REG_SHD_HEATR_DUR                  UINT8_C(0x6E)

/* CTRL_GAS_0 address */
#define BME68X_REG_CTRL_GAS_0                     UINT8_C(0x70)

/* CTRL_GAS_1 address */
#define BME68X_REG_CTRL_GAS_1                     UINT8_C(0x71)

/* CTRL_HUM address */
#define BME68X_REG_CTRL_HUM                       UINT8_C(0x72)

/* CTRL_MEAS address */
#define BME68X_REG_CTRL_MEAS                      UINT8_C(0x74)

/* CONFIG address */
#define BME68X_REG_CONFIG                         UINT8_C(0x75)

/* MEM_PAGE address */
#define BME68X_REG_MEM_PAGE                       UINT8_C(0xf3)

/* Unique ID address */
#define BME68X_REG_UNIQUE_ID                      UINT8_C(0x83)
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

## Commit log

2023-09-19 First release
    [bsec_iaq.csv]
2023-09-20 Upload HW files
    [BOM.xlsx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]
